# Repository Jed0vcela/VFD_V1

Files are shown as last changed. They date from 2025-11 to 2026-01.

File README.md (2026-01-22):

VFD driver for IVL1-8/13 soviet display.
Powered form 5V USB.
SPI interface that can be daisy-chained.
3,3V logic level.
Analog dimming via adjusting anode voltage.
Heater voltage adjustment implemented on board but not tested




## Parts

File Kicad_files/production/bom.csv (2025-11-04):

Designator | Footprint | Quantity | Value | LCSC Part #
27V1, 3V1, 8V1, GND1 | TestPoint_Pad_D1.0mm | 4 | TestPoint_Probe
C1, C4, C9 | 1206 | 3 | 1u
C12, C13, C14, C15 | 0805 | 4 | 100n
C2 | CP_Radial_D8.0mm_P5.00mm | 1 | 470u
C5, C6 | 0805 | 2 | 470p
C8 | CP_Radial_D8.0mm_P5.00mm | 1 | 100u
D1, D3, D4, D5 | D_SOD-323_HandSoldering | 4 | LL4148
J1 | PinHeader_1x08_P2.54mm_Horizontal | 1 | Conn_01x08_Pin
J2 | PinSocket_1x08_P2.54mm_Horizontal | 1 | Conn_01x08_Socket
L1 | L_7.3x7.3_H4.5 | 1 | DE1205-330
Q1, Q10, Q12, Q14, Q16, Q18, Q19, Q2, Q21, Q23, Q25, Q27, Q29, Q31, Q33, Q35, Q36, Q38, Q4, Q40, Q42, Q44, Q46, Q48, Q50, Q6, Q8 | SOT-23 | 27 | BC846
Q11, Q13, Q15, Q17, Q20, Q22, Q24, Q26, Q28, Q3, Q30, Q32, Q34, Q37, Q39, Q41, Q43, Q45, Q47, Q49, Q5, Q51, Q7, Q9 | SOT-23 | 24 | BC856
R1 | 0805 | 1 | 1,8
R10 | 0805 | 1 | 470k
R11 | 0805 | 1 | 220k
R12, R15, R17, R18, R22, R23, R24, R25, R26, R28, R29, R30, R40, R41, R42, R43, R44, R46, R47, R48, R57, R58, R59, R60, R61, R63, R64, R65, R8 | 0805 | 29 | 100k
R13 | 0805 | 1 | 22k
R19 | 0805 | 1 | 56k
R2 | 0805 | 1 | 470m
R20 | 0805 | 1 | 27k
R21, R39, R56 | 0805 | 3 | 10k
R3, R4 | 0805 | 2 | 180
R5 | 0805 | 1 | 1M
R6, R7 | 0805 | 2 | 0
R9 | 0805 | 1 | 4k7
U10, U11, U8 | SOIC-16_3.9x9.9mm_P1.27mm | 3 | ULN2003
U2 | SOIC-8_3.9x4.9mm_P1.27mm | 1 | MC34063AD
U4 | IVL1-813 | 1 | IVL1-8/13
U5, U6, U7, U9 | SOIC-16_3.9x9.9mm_P1.27mm | 4 | 74AHC595

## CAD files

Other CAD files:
Kicad_files/3D files/M1005_cap_004.SLDASM
Kicad_files/3D files/Side_metal001.SLDASM
Kicad_files/3D files/M1005_res_0.2_001.SLDASM
Kicad_files/3D files/Side.SLDASM
Kicad_files/3D files/M0603_cap_0.3_007.SLDASM
Kicad_files/3D files/RT6154AGQW.SLDASM
Kicad_files/3D files/Pins001.SLDASM
Kicad_files/3D files/M1005_cap_003.SLDASM
Kicad_files/3D files/Misc.SLDASM
Kicad_files/3D files/Button_v2.SLDASM
Kicad_files/3D files/LED_M1608.SLDASM
Kicad_files/3D files/Pins1.SLDASM
Kicad_files/3D files/Part006.SLDASM
Kicad_files/3D files/M0603_cap_0.3_001.SLDASM
Kicad_files/3D files/M0603_cap_0.3_003.SLDASM
Kicad_files/3D files/M2012_cap003.SLDASM
Kicad_files/3D files/Part005.SLDASM
Kicad_files/3D files/Part004.SLDASM
Kicad_files/3D files/0C-138.SLDPRT
Kicad_files/3D files/1.15.SLDPRT
Kicad_files/3D files/2.SLDPRT
Kicad_files/3D files/2001.SLDPRT
Kicad_files/3D files/3V3.SLDPRT
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

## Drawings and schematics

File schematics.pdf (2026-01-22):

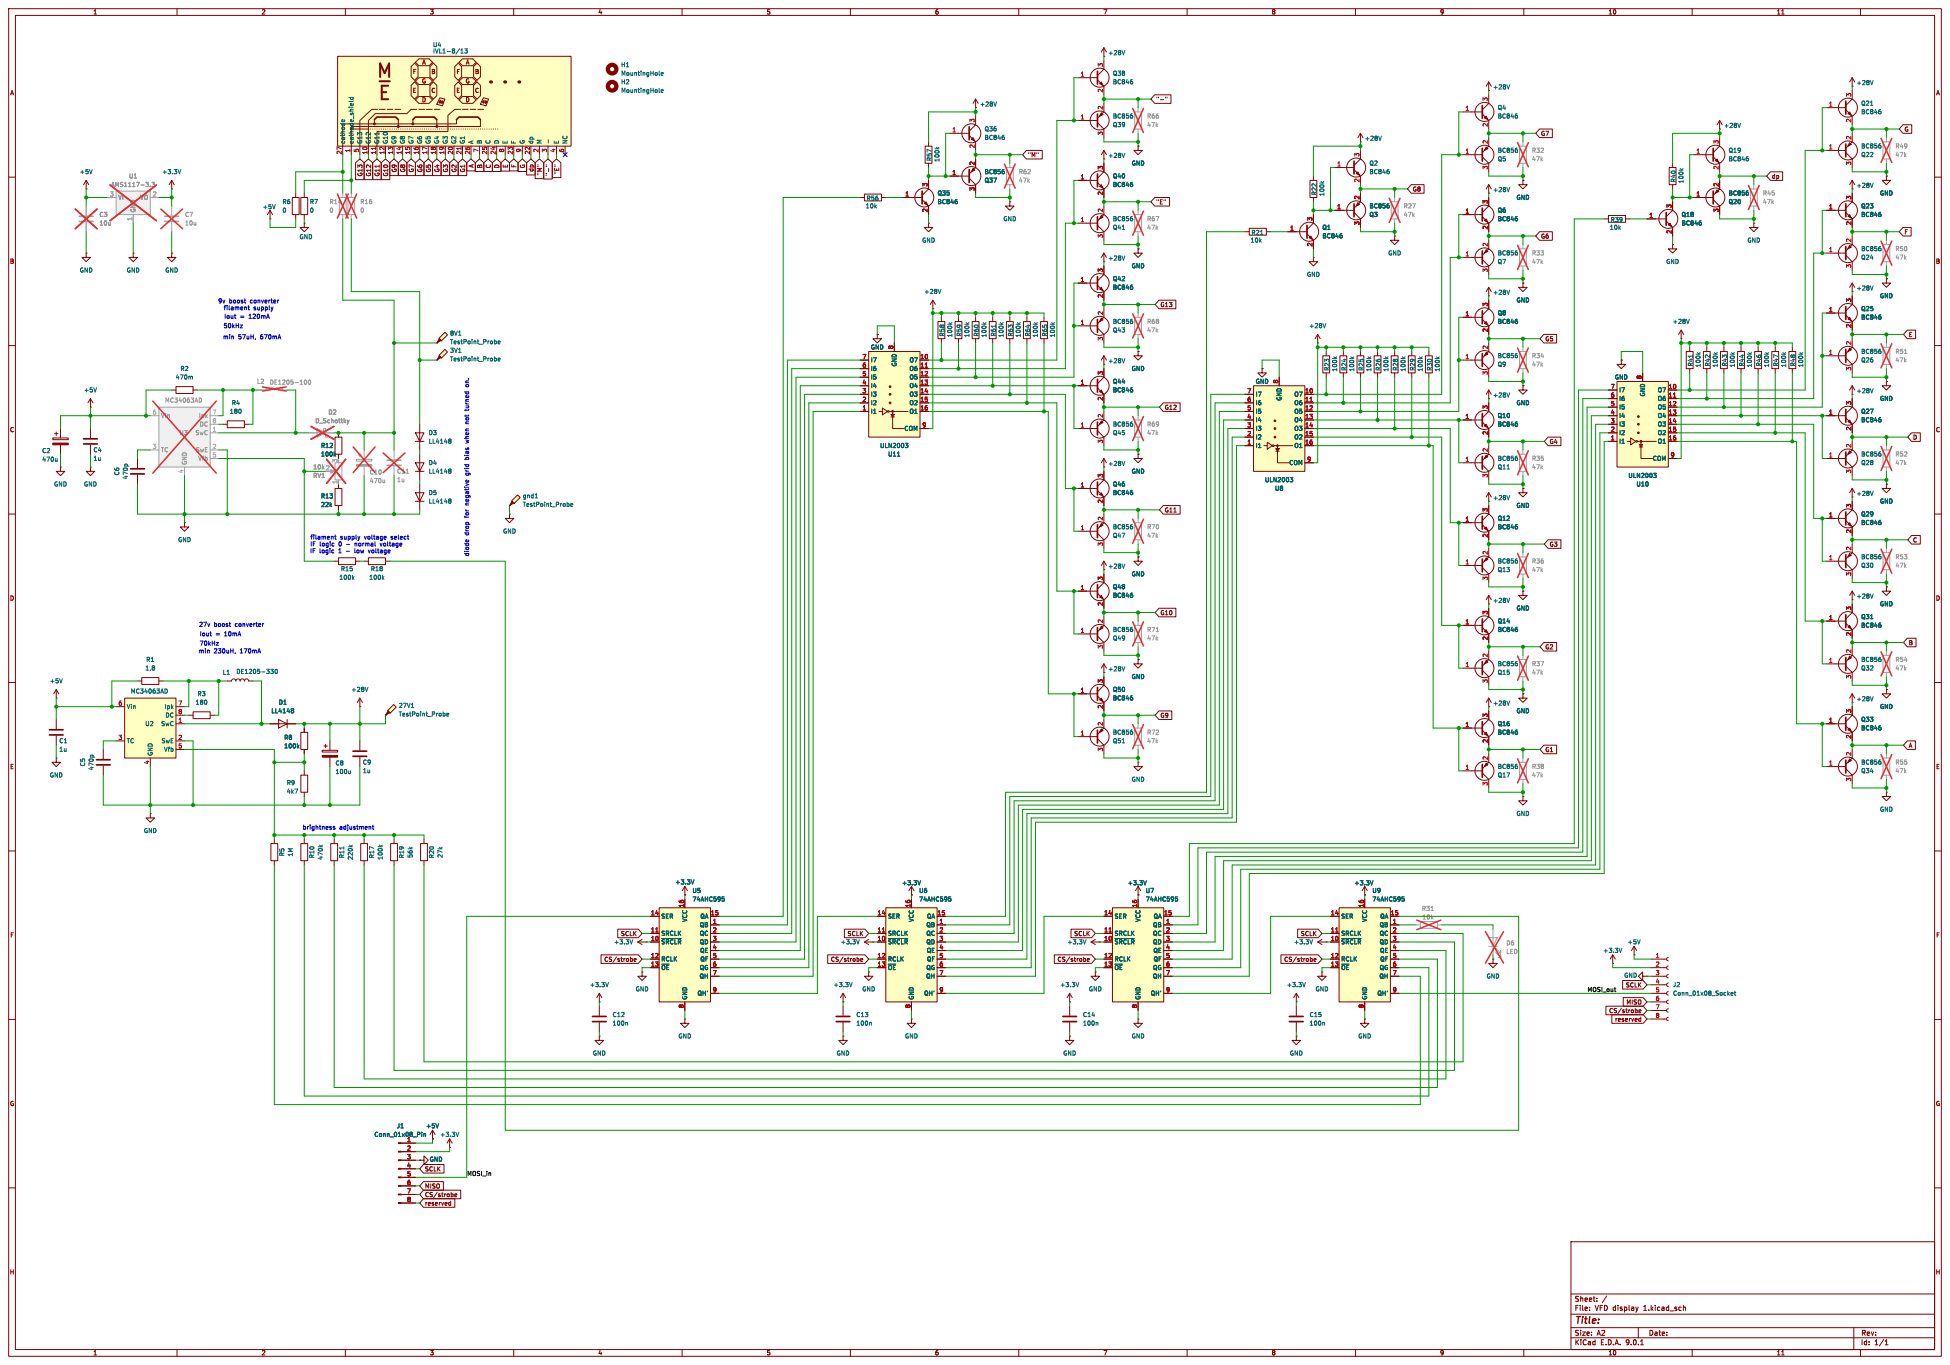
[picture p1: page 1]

Ipk 7 DC 8 SwC 1 SwE 2 Vfb 5 U3 MC34063AD

IF logic 0 - normal voltage

Ipk 7 DC 8 SwC 1 SwE 2 Vfb 5 U2 MC34063AD C5 470p GND

74AHC595

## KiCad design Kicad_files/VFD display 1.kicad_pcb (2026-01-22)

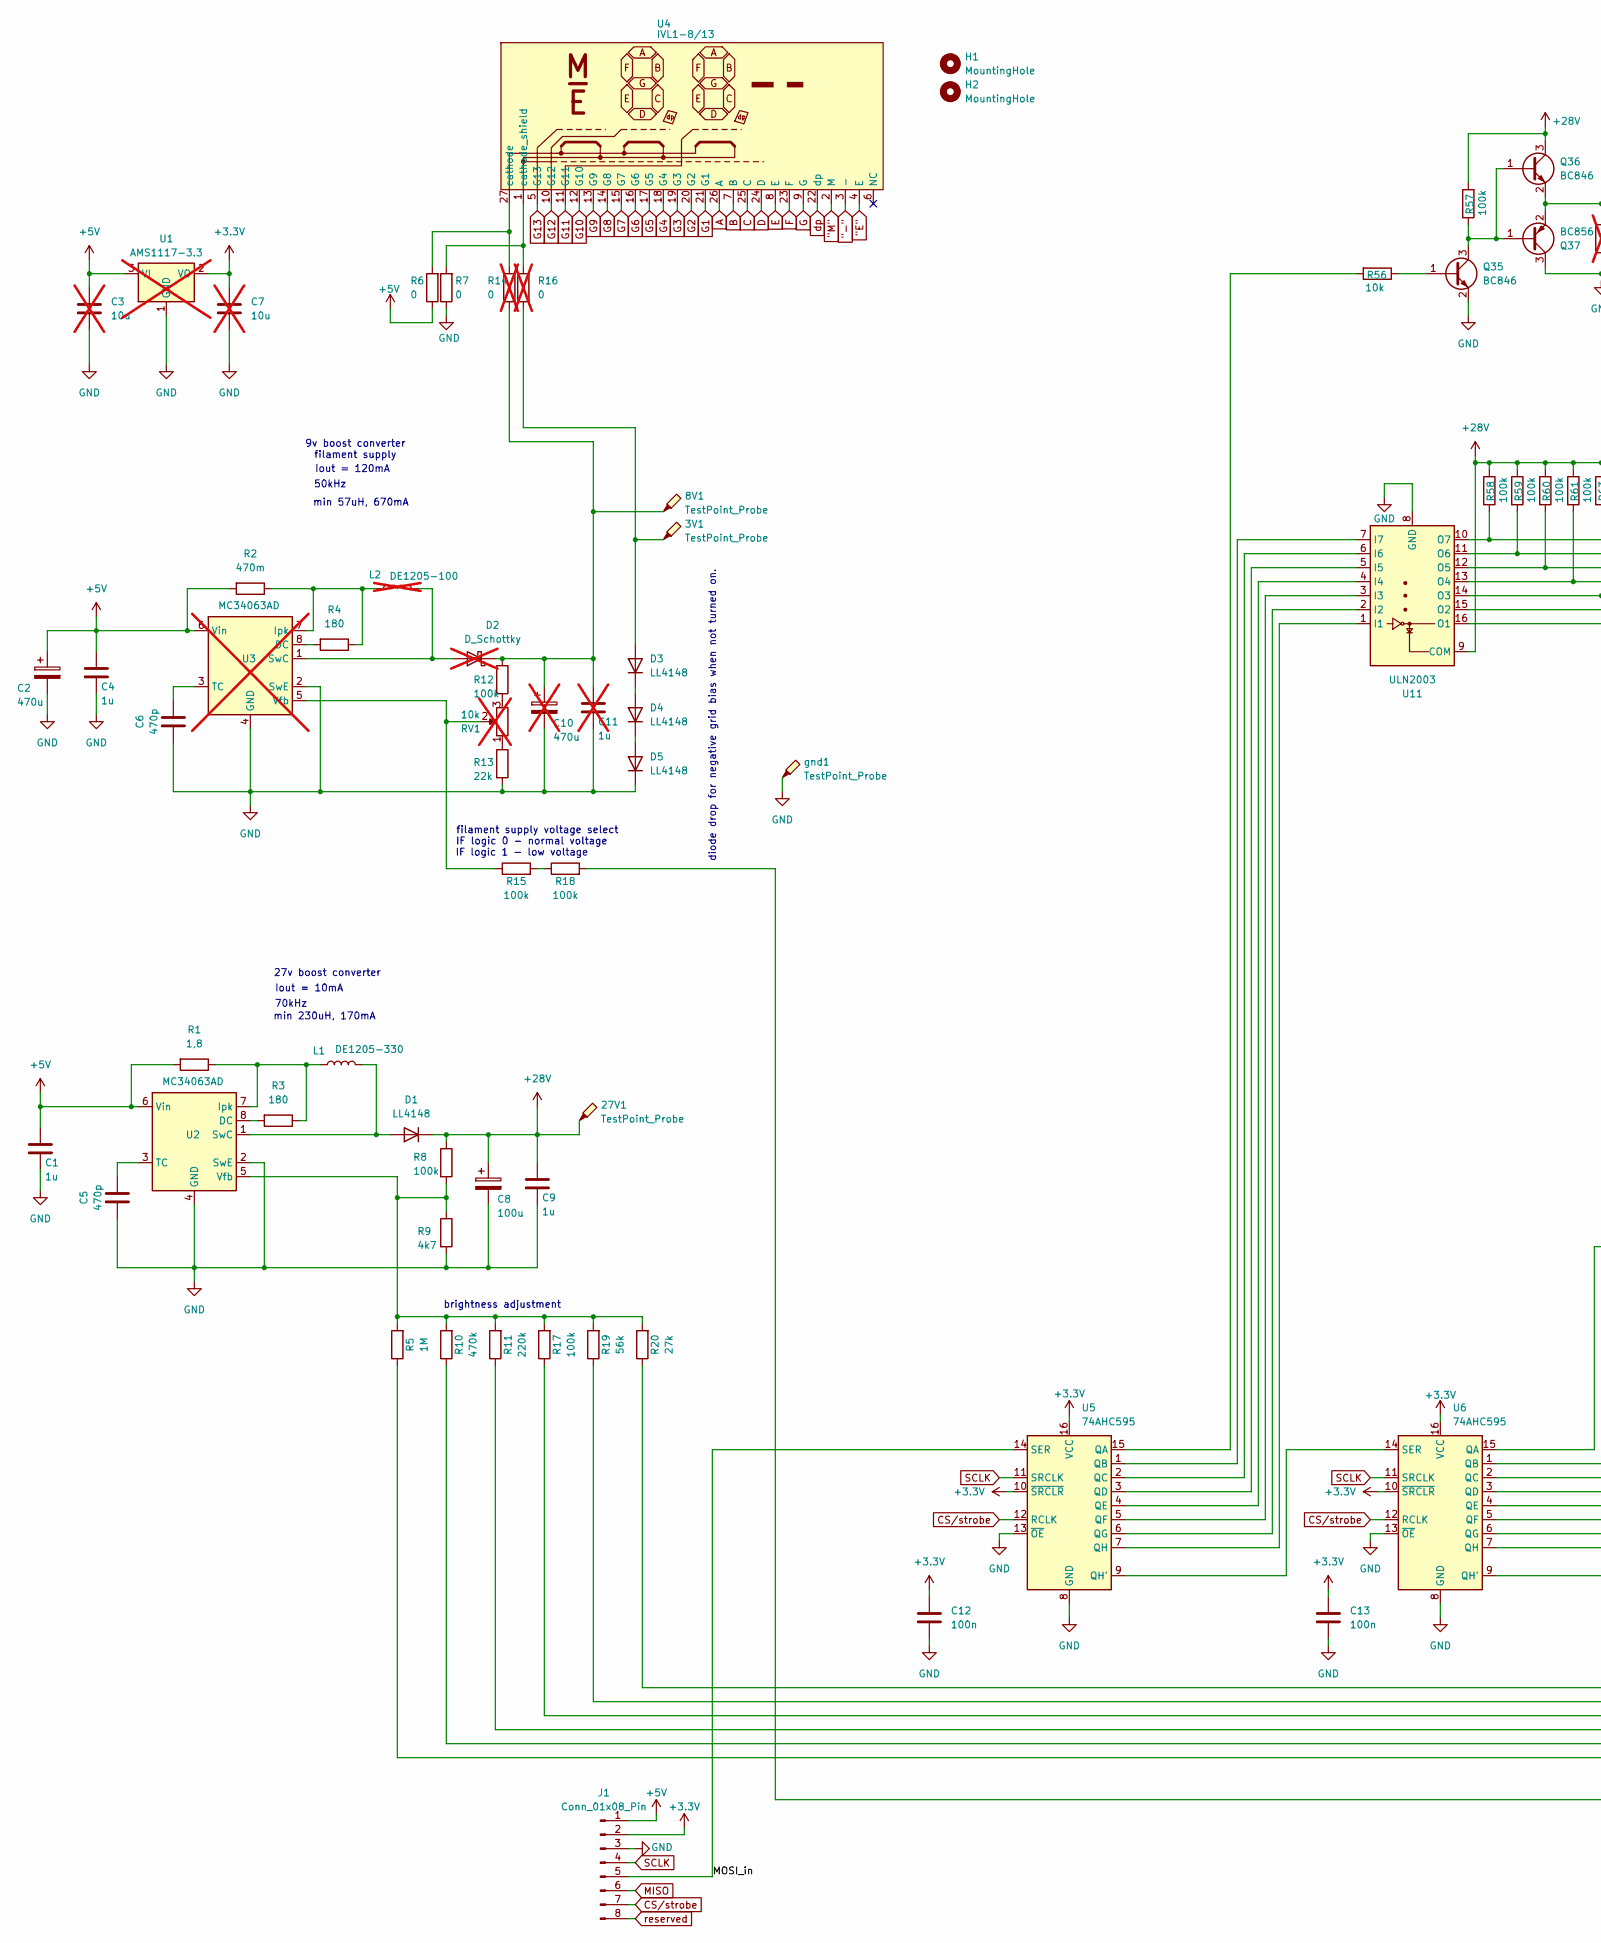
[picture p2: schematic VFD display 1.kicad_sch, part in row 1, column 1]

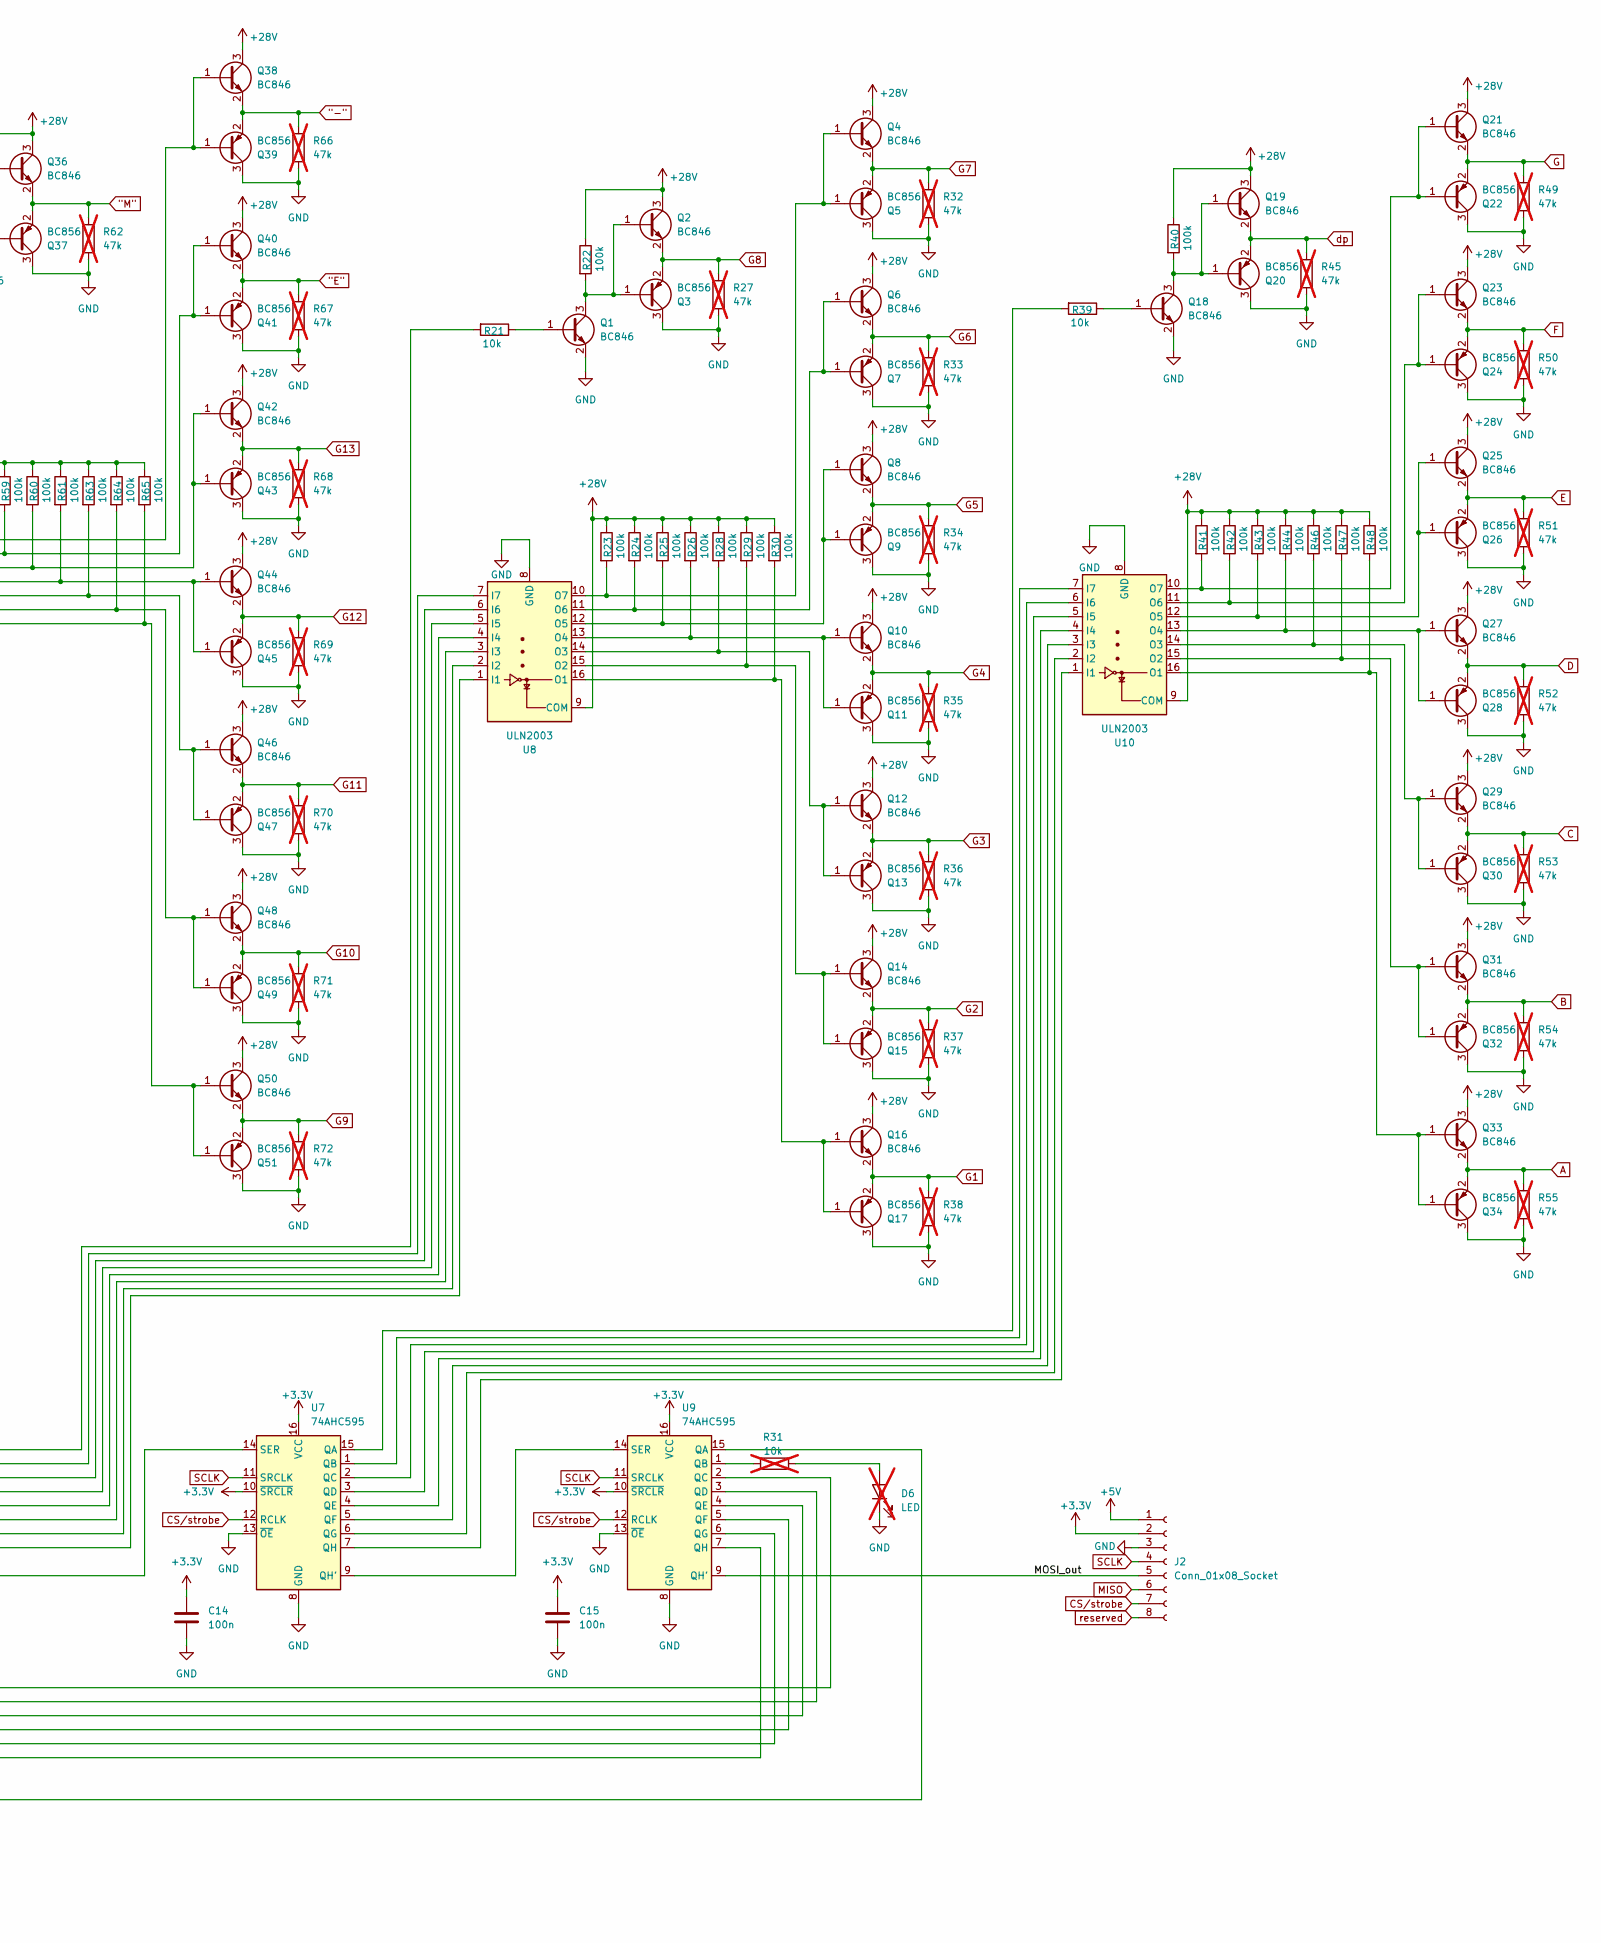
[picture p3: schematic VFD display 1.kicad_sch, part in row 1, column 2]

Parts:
3V1, 8V1, 27V1: TestPoint_Probe; TestPoint_Pad_D1.0mm
C1, C4, C9: 1u; C_1206_3216Metric_Pad1.33x1.80mm_HandSolder
C2: 470u; CP_Radial_D8.0mm_P5.00mm
C3, C7: 10u; C_0805_2012Metric; not fitted
C5, C6: 470p; C_0805_2012Metric
C8: 100u; CP_Radial_D8.0mm_P5.00mm
C10: 470u; CP_Radial_D8.0mm_P5.00mm; not fitted
C11: 1u; C_1206_3216Metric_Pad1.33x1.80mm_HandSolder; not fitted
C12, C13, C14, C15: 100n; C_0805_2012Metric_Pad1.18x1.45mm_HandSolder
D1, D3, D4, D5: LL4148; D_SOD-323_HandSoldering
D2: D_Schottky; D_SMA; not fitted
D6: LED; LED_0805_2012Metric; not fitted
H1, H2: MountingHole; MountingHole_3.2mm_M3_DIN965
J1: Conn_01x08_Pin; PinHeader_1x08_P2.54mm_Horizontal
J2: Conn_01x08_Socket; PinSocket_1x08_P2.54mm_Horizontal
L1: DE1205-330; L_7.3x7.3_H4.5
L2: DE1205-100; L_12x12mm_H6mm; not fitted
Q1, Q2, Q4, Q6, Q8, Q10, Q12, Q14, Q16, Q18, Q19, Q21, Q23, Q25, Q27, Q29, Q31, Q33, Q35, Q36, Q38, Q40, Q42, Q44, Q46, Q48, Q50: BC846; SOT-23
Q3, Q5, Q7, Q9, Q11, Q13, Q15, Q17, Q20, Q22, Q24, Q26, Q28, Q30, Q32, Q34, Q37, Q39, Q41, Q43, Q45, Q47, Q49, Q51: BC856; SOT-23
R1: 1,8; R_0805_2012Metric
R2: 470m; R_0805_2012Metric
R3, R4: 180; R_0805_2012Metric
R5: 1M; R_0805_2012Metric_Pad1.20x1.40mm_HandSolder
R6, R7: 0; R_0805_2012Metric_Pad1.20x1.40mm_HandSolder
R8, R12: 100k; R_0805_2012Metric
R9: 4k7; R_0805_2012Metric
R10: 470k; R_0805_2012Metric_Pad1.20x1.40mm_HandSolder
R11: 220k; R_0805_2012Metric_Pad1.20x1.40mm_HandSolder
R13: 22k; R_0805_2012Metric
R14, R16: 0; R_0805_2012Metric_Pad1.20x1.40mm_HandSolder; not fitted
R15, R17, R18, R22, R23, R24, R25, R26, R28, R29, R30, R40, R41, R42, R43, R44, R46, R47, R48, R57, R58, R59, R60, R61, R63, R64, R65: 100k; R_0805_2012Metric_Pad1.20x1.40mm_HandSolder
R19: 56k; R_0805_2012Metric_Pad1.20x1.40mm_HandSolder
R20: 27k; R_0805_2012Metric_Pad1.20x1.40mm_HandSolder
R21, R39, R56: 10k; R_0805_2012Metric_Pad1.20x1.40mm_HandSolder
R27, R32, R33, R34, R35, R36, R37, R38, R45, R49, R50, R51, R52, R53, R54, R55, R62, R66, R67, R68, R69, R70, R71, R72: 47k; R_0805_2012Metric_Pad1.20x1.40mm_HandSolder; not fitted
R31: 10k; R_0805_2012Metric_Pad1.20x1.40mm_HandSolder; not fitted
RV1: 10k; Potentiometer_Piher_PT-6-V_Vertical_Hole; not fitted
U1: AMS1117-3.3; SOT-223-3_TabPin2; not fitted
U2: MC34063AD; SOIC-8_3.9x4.9mm_P1.27mm
U3: MC34063AD; SOIC-8_3.9x4.9mm_P1.27mm; not fitted
U4: IVL1-8/13; IVL1-813
U5, U6, U7, U9: 74AHC595; SOIC-16_3.9x9.9mm_P1.27mm
U8, U10, U11: ULN2003; SOIC-16_3.9x9.9mm_P1.27mm
gnd1: TestPoint_Probe; TestPoint_Pad_D1.0mm

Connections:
"-": Q38.2 (E), Q39.2 (E), R66.1, U4.3 (-)
"E": Q40.2 (E), Q41.2 (E), R67.1, U4.4 (E)
"M": Q36.2 (E), Q37.2 (E), R62.1, U4.2 (M)
+3.3V: C7.1, C12.1, C13.1, C14.1, C15.1, J1.2, J2.2, U1.2 (VO), U5.10 (~SRCLR), U5.16 (VCC), U6.10 (~SRCLR), U6.16 (VCC), U7.10 (~SRCLR), U7.16 (VCC), U9.10 (~SRCLR), U9.16 (VCC)
+5V: C1.1, C2.1, C3.1, C4.1, J1.1, J2.1, R1.2, R2.2, R6.1, U1.3 (VI), U2.6 (Vin), U3.6 (Vin)
+28V: 27V1.1, C8.1, C9.1, D1.1 (K), Q2.3 (C), Q4.3 (C), Q6.3 (C), Q8.3 (C), Q10.3 (C), Q12.3 (C), Q14.3 (C), Q16.3 (C), Q19.3 (C), Q21.3 (C), Q23.3 (C), Q25.3 (C), Q27.3 (C), Q29.3 (C), Q31.3 (C), Q33.3 (C), Q36.3 (C), Q38.3 (C), Q40.3 (C), Q42.3 (C), Q44.3 (C), Q46.3 (C), Q48.3 (C), Q50.3 (C), R8.1, R22.1, R23.1, R24.1, R25.1, R26.1, R28.1, R29.1, R30.1, R40.1, R41.1, R42.1, R43.1, R44.1, R46.1, R47.1, R48.1, R57.1, R58.1, R59.1, R60.1, R61.1, R63.1, R64.1, R65.1, U8.9 (COM), U10.9 (COM), U11.9 (COM)
/MOSI_in: J1.5, U5.14 (SER)
/MOSI_out: J2.5, U9.9 (QH')
A: Q33.2 (E), Q34.2 (E), R55.1, U4.26 (A)
B: Q31.2 (E), Q32.2 (E), R54.1, U4.7 (B)
C: Q29.2 (E), Q30.2 (E), R53.1, U4.25 (C)
CS/strobe: J1.7, J2.7, U5.12 (RCLK), U6.12 (RCLK), U7.12 (RCLK), U9.12 (RCLK)
D: Q27.2 (E), Q28.2 (E), R52.1, U4.24 (D)
E: Q25.2 (E), Q26.2 (E), R51.1, U4.8 (E)
F: Q23.2 (E), Q24.2 (E), R50.1, U4.23 (F)
G: Q21.2 (E), Q22.2 (E), R49.1, U4.9 (G)
G1: Q16.2 (E), Q17.2 (E), R38.1, U4.21 (G1)
G2: Q14.2 (E), Q15.2 (E), R37.1, U4.20 (G2)
G3: Q12.2 (E), Q13.2 (E), R36.1, U4.19 (G3)
G4: Q10.2 (E), Q11.2 (E), R35.1, U4.18 (G4)
G5: Q8.2 (E), Q9.2 (E), R34.1, U4.17 (G5)
G6: Q6.2 (E), Q7.2 (E), R33.1, U4.16 (G6)
G7: Q4.2 (E), Q5.2 (E), R32.1, U4.15 (G7)
G8: Q2.2 (E), Q3.2 (E), R27.1, U4.14 (G8)
G9: Q50.2 (E), Q51.2 (E), R72.1, U4.13 (G9)
G10: Q48.2 (E), Q49.2 (E), R71.1, U4.12 (G10)
G11: Q46.2 (E), Q47.2 (E), R70.1, U4.11 (G11)
G12: Q44.2 (E), Q45.2 (E), R69.1, U4.10 (G12)
G13: Q42.2 (E), Q43.2 (E), R68.1, U4.5 (G13)
GND: C1.2, C2.2, C3.2, C4.2, C5.1, C6.1, C7.2, C8.2, C9.2, C10.2, C11.2, C12.2, C13.2, C14.2, C15.2, D5.1 (K), D6.1 (K), J1.3, J2.3, Q1.2 (E), Q3.3 (C), Q5.3 (C), Q7.3 (C), Q9.3 (C), Q11.3 (C), Q13.3 (C), Q15.3 (C), Q17.3 (C), Q18.2 (E), Q20.3 (C), Q22.3 (C), Q24.3 (C), Q26.3 (C), Q28.3 (C), Q30.3 (C), Q32.3 (C), Q34.3 (C), Q35.2 (E), Q37.3 (C), Q39.3 (C), Q41.3 (C), Q43.3 (C), Q45.3 (C), Q47.3 (C), Q49.3 (C), Q51.3 (C), R7.1, R9.2, R13.2, R27.2, R32.2, R33.2, R34.2, R35.2, R36.2, R37.2, R38.2, R45.2, R49.2, R50.2, R51.2, R52.2, R53.2, R54.2, R55.2, R62.2, R66.2, R67.2, R68.2, R69.2, R70.2, R71.2, R72.2, U1.1 (GND), U2.2 (SwE), U2.4 (GND), U3.2 (SwE), U3.4 (GND), U5.8 (GND), U5.13 (~OE), U6.8 (GND), U6.13 (~OE), U7.8 (GND), U7.13 (~OE), U8.8 (GND), U9.8 (GND), U9.13 (~OE), U10.8 (GND), U11.8 (GND), gnd1.1
MISO: J1.6, J2.6
unnamed: D1.2 (A), L1.2, U2.1 (SwC)
unnamed: D2.2 (A), L2.2, U3.1 (SwC)
unnamed: 8V1.1, C10.1, C11.1, D2.1 (K), R12.1, R14.1
unnamed: 3V1.1, D3.2 (A), R16.1
unnamed: D3.1 (K), D4.2 (A)
unnamed: D4.1 (K), D5.2 (A)
unnamed: D6.2 (A), R31.2
unnamed: Q1.1 (B), R21.1
unnamed: Q1.3 (C), Q2.1 (B), Q3.1 (B), R22.2
unnamed: Q4.1 (B), Q5.1 (B), R23.2, U8.10 (O7)
unnamed: Q6.1 (B), Q7.1 (B), R24.2, U8.11 (O6)
unnamed: Q8.1 (B), Q9.1 (B), R25.2, U8.12 (O5)
unnamed: Q10.1 (B), Q11.1 (B), R26.2, U8.13 (O4)
unnamed: Q12.1 (B), Q13.1 (B), R28.2, U8.14 (O3)
unnamed: Q14.1 (B), Q15.1 (B), R29.2, U8.15 (O2)
unnamed: Q16.1 (B), Q17.1 (B), R30.2, U8.16 (O1)
unnamed: Q18.1 (B), R39.1
unnamed: Q18.3 (C), Q19.1 (B), Q20.1 (B), R40.2
unnamed: Q21.1 (B), Q22.1 (B), R41.2, U10.10 (O7)
unnamed: Q23.1 (B), Q24.1 (B), R42.2, U10.11 (O6)
unnamed: Q25.1 (B), Q26.1 (B), R43.2, U10.12 (O5)
unnamed: Q27.1 (B), Q28.1 (B), R44.2, U10.13 (O4)
unnamed: Q29.1 (B), Q30.1 (B), R46.2, U10.14 (O3)
unnamed: Q31.1 (B), Q32.1 (B), R47.2, U10.15 (O2)
unnamed: Q33.1 (B), Q34.1 (B), R48.2, U10.16 (O1)
unnamed: Q35.1 (B), R56.1
unnamed: Q35.3 (C), Q36.1 (B), Q37.1 (B), R57.2
unnamed: Q38.1 (B), Q39.1 (B), R58.2, U11.10 (O7)
unnamed: Q40.1 (B), Q41.1 (B), R59.2, U11.11 (O6)
unnamed: Q42.1 (B), Q43.1 (B), R60.2, U11.12 (O5)
unnamed: Q44.1 (B), Q45.1 (B), R61.2, U11.13 (O4)
unnamed: Q46.1 (B), Q47.1 (B), R63.2, U11.14 (O3)
unnamed: Q48.1 (B), Q49.1 (B), R64.2, U11.15 (O2)
unnamed: Q50.1 (B), Q51.1 (B), R65.2, U11.16 (O1)
unnamed: R12.2, RV1.3
unnamed: R13.1, RV1.1
unnamed: R15.2, R18.1
unnamed: R3.2, U2.8 (DC)
unnamed: L1.1, R1.1, R3.1, U2.7 (Ipk)
unnamed: C5.2, U2.3 (TC)
unnamed: R5.2, R8.2, R9.1, R10.2, R11.2, R17.2, R19.2, R20.2, U2.5 (Vfb)
unnamed: R4.2, U3.8 (DC)
unnamed: L2.1, R2.1, R4.1, U3.7 (Ipk)
unnamed: C6.2, U3.3 (TC)
unnamed: R15.1, RV1.2, U3.5 (Vfb)
unnamed: R6.2, R14.2, U4.27 (cathode)
unnamed: R7.2, R16.2, U4.1 (cathode_shield)
unnamed: R56.2, U5.15 (QA)
unnamed: U5.9 (QH'), U6.14 (SER)
unnamed: R21.2, U6.15 (QA)
unnamed: U6.1 (QB), U8.7 (I7)
unnamed: U6.2 (QC), U8.6 (I6)
unnamed: U6.3 (QD), U8.5 (I5)
unnamed: U6.4 (QE), U8.4 (I4)
unnamed: U6.5 (QF), U8.3 (I3)
unnamed: U6.6 (QG), U8.2 (I2)
unnamed: U6.9 (QH'), U7.14 (SER)
unnamed: U6.7 (QH), U8.1 (I1)
unnamed: R39.2, U7.15 (QA)
unnamed: U7.9 (QH'), U9.14 (SER)
unnamed: R18.2, U9.15 (QA)
unnamed: R31.1, U9.1 (QB)
unnamed: R20.1, U9.2 (QC)
unnamed: R19.1, U9.3 (QD)
unnamed: R17.1, U9.4 (QE)
unnamed: R11.1, U9.5 (QF)
unnamed: R10.1, U9.6 (QG)
unnamed: R5.1, U9.7 (QH)
unnamed: U7.7 (QH), U10.1 (I1)
unnamed: U7.6 (QG), U10.2 (I2)
unnamed: U7.5 (QF), U10.3 (I3)
unnamed: U7.4 (QE), U10.4 (I4)
unnamed: U7.3 (QD), U10.5 (I5)
unnamed: U7.2 (QC), U10.6 (I6)
unnamed: U7.1 (QB), U10.7 (I7)
unnamed: U5.7 (QH), U11.1 (I1)
unnamed: U5.6 (QG), U11.2 (I2)
unnamed: U5.5 (QF), U11.3 (I3)
unnamed: U5.4 (QE), U11.4 (I4)
unnamed: U5.3 (QD), U11.5 (I5)
unnamed: U5.2 (QC), U11.6 (I6)
unnamed: U5.1 (QB), U11.7 (I7)
SCLK: J1.4, J2.4, U5.11 (SRCLK), U6.11 (SRCLK), U7.11 (SRCLK), U9.11 (SRCLK)
dp: Q19.2 (E), Q20.2 (E), R45.1, U4.22 (dp)
reserved: J1.8, J2.8

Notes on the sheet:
70kHz
50kHz
min 230uH, 170mA
filament supply voltage select
Iout = 120mA
min 57uH, 670mA
27v boost converter
diode drop for negative grid bias when not turned on.
9v boost converter filament supply
brightness adjustment
IF logic 0 - normal voltage
IF logic 1 - low voltage
Iout = 10mA

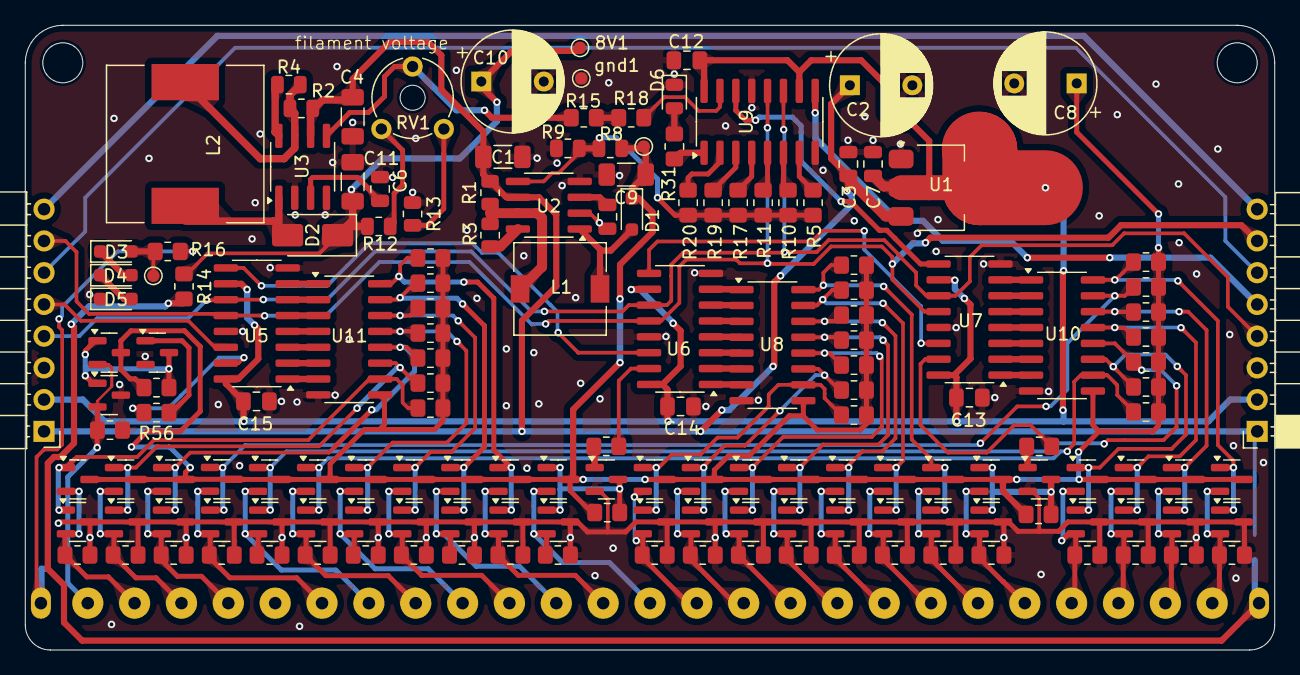
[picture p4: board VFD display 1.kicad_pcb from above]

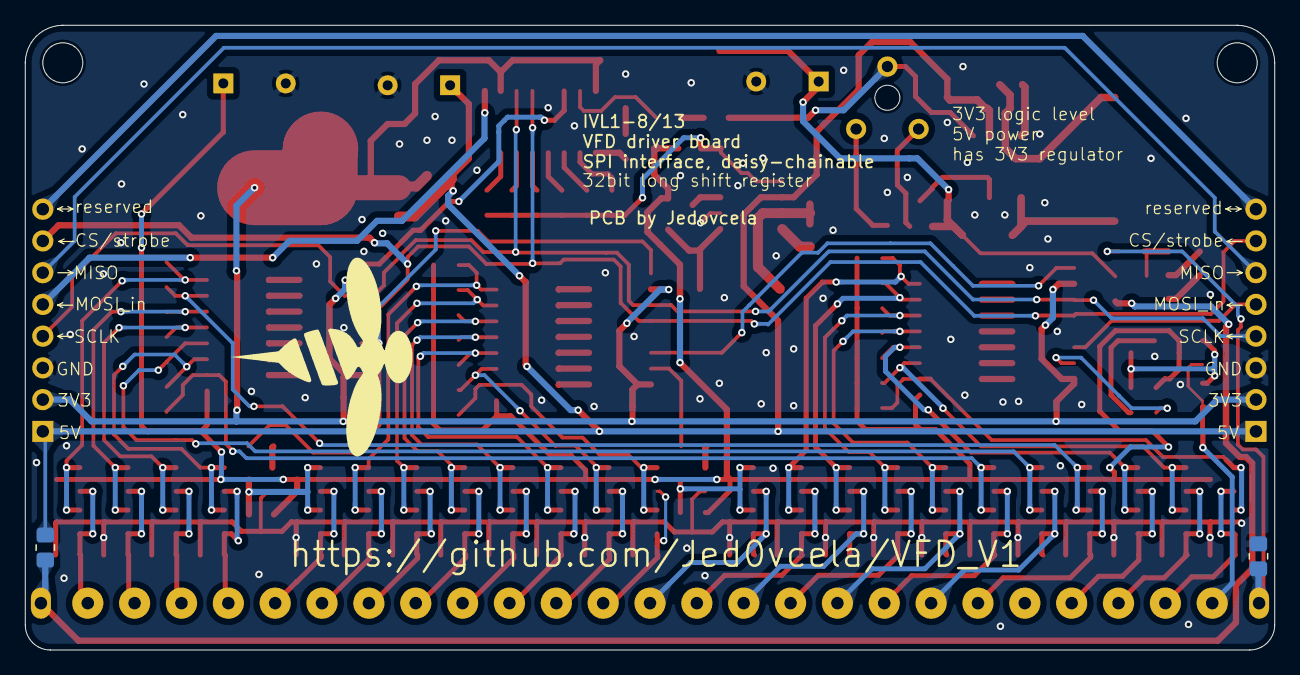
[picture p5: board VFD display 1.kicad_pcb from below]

Board: 2 copper layers, 100.0 x 50.0 mm, 166 parts (2 on the bottom side), 116 nets.

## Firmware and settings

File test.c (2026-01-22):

#include <stdio.h>
#include "pico/stdlib.h"
#include "hardware/spi.h"

// SPI pins
#define PIN_SCK  2
#define PIN_MOSI 3
#define PIN_MISO 4  // unused but needed for SPI init
#define PIN_CS   5  // latch pin

// Button pins (active low with pullup)
#define BTN_TIME_UP    17
#define BTN_TIME_DOWN  18
#define BTN_BRIGHT_UP  21
#define BTN_BRIGHT_DOWN 22

// SPI instance
#define SPI_PORT spi0
#define SPI_BAUDRATE 1000000  // 1 MHz

// Display parameters
#define NUM_DIGITS 13
#define NUM_SPECIAL 3

// Special character bit positions (bits 0-2 in digit mask after rotation)
#define SPECIAL_M_BIT 0  // "M" character (last bit sent over SPI)
#define SPECIAL_DASH_BIT 1  // "-" character
#define SPECIAL_E_BIT 2  // "E" character

// Digit positions are shifted right by 3 (bits 3-15)
#define DIGIT_BIT_OFFSET 3

// Global variables
uint8_t brightness = 30;  // 0-63
uint8_t digit = 0;

int32_t time_offset_seconds = 0;  // User adjustment

// Special character enable flags
bool special_m_enabled = false;
bool special_dash_enabled = false;
bool special_e_enabled = false;

// Button state tracking
typedef struct {
    uint8_t pin;
    bool pressed;
    uint32_t press_start_time;
    uint32_t last_action_time;
    uint32_t hold_count;
} button_state_t;

button_state_t btn_time_up = {BTN_TIME_UP, false, 0, 0, 0};
button_state_t btn_time_down = {BTN_TIME_DOWN, false, 0, 0, 0};
button_state_t btn_bright_up = {BTN_BRIGHT_UP, false, 0, 0, 0};
button_state_t btn_bright_down = {BTN_BRIGHT_DOWN, false, 0, 0, 0};

// 7-segment lookup table
const uint8_t seg7[12] = {
    0x11,        // 0
    0b11011011,  // 1
    0b01000101,  // 2
    0b01001001,  // 3
    0b10001011,  // 4
    0b00101001,  // 5
    0b00100001,  // 6
    0b01011011,  // 7
    0x01,        // 8
    0x09,        // 9
    0xff,        // blank
    0xfe         // dash
};

// Bit reversal table for 6-bit values
const uint8_t rev6[64] = {
    0,32,16,48,8,40,24,56,4,36,20,52,12,44,28,60,
    2,34,18,50,10,42,26,58,6,38,22,54,14,46,30,62,
    1,33,17,49,9,41,25,57,5,37,21,53,13,45,29,61,
    3,35,19,51,11,43,27,59,7,39,23,55,15,47,31,63
};

// Number array for 13 digits, initialization
uint8_t number[NUM_DIGITS] = {10,10,10,10,4,5,6,7,8,9,5,7,3};

/**
 * Send 32 bits via SPI and pulse latch pin
 */
void send_32bit(uint32_t value) {
    uint8_t buf[4];
    
    // Split into 4 bytes (MSB first)
    buf[0] = (value >> 24) & 0xFF;
    buf[1] = (value >> 16) & 0xFF;
    buf[2] = (value >> 8)  & 0xFF;
    buf[3] = value & 0xFF;
    
    // Send via SPI
    spi_write_blocking(SPI_PORT, buf, 4);
    
    // Pulse latch/CS pin
    gpio_put(PIN_CS, 1);
    sleep_us(1);
    gpio_put(PIN_CS, 0);
}

/**
 * Send display data for one digit (0-12)
 */
void send_display_digit(uint8_t dig) {
    uint32_t bright, num, dig_mask, frame;
    
    // Clamp brightness to 6 bits
    if (brightness > 63) {
        brightness = 63;
    }
    
    // Reverse brightness bits and shift to position [31:26]
    bright = rev6[brightness];
    bright = bright << 26;
    bright = (~bright) & 0xFC000000;
    
    uint8_t tmp_num = number[dig];
    
    // Segment data in bits [23:16]
    num = ((uint32_t)seg7[tmp_num]) << 16;
    
    // Digit mask: digits are in bits [15:3], special chars in bits [2:0]
    dig_mask = 1 << (dig + DIGIT_BIT_OFFSET);
    dig_mask = (~dig_mask) & 0x0000FFF8;

    uint32_t special = (!special_e_enabled << 2) | (!special_dash_enabled << 1) | !special_m_enabled;

    // Combine and send
    frame = bright + num + dig_mask + special;
    send_32bit(frame);
}

/**
 * Update a specific digit value
 */
void set_digit_value(uint8_t pos, uint8_t value) {
    if (pos < NUM_DIGITS) {
        number[pos] = value;
    }
}

/**
 * Set brightness (0-63)
 */
void set_brightness(uint8_t bright) {
    if (bright > 63) {
        bright = 63;
    }
    brightness = bright;
}

/**
 * Initialize buttons with pullup
 */
void init_buttons(void) {
    gpio_init(BTN_TIME_UP);
    gpio_set_dir(BTN_TIME_UP, GPIO_IN);
    gpio_pull_up(BTN_TIME_UP);
    
    gpio_init(BTN_TIME_DOWN);
    gpio_set_dir(BTN_TIME_DOWN, GPIO_IN);
    gpio_pull_up(BTN_TIME_DOWN);
    
    gpio_init(BTN_BRIGHT_UP);
    gpio_set_dir(BTN_BRIGHT_UP, GPIO_IN);
    gpio_pull_up(BTN_BRIGHT_UP);
    
    gpio_init(BTN_BRIGHT_DOWN);
    gpio_set_dir(BTN_BRIGHT_DOWN, GPIO_IN);
    gpio_pull_up(BTN_BRIGHT_DOWN);
}

/**
 * Calculate time adjustment with smooth linear acceleration
 * Returns number of seconds to adjust based on hold duration
 */
int32_t calculate_time_adjustment(uint32_t hold_count) {
    // Linear acceleration: starts at 1 second, increases smoothly
    
    int32_t adjustment = 1 + (hold_count / 2);
    
    return adjustment;
}

/**
 * Process button state with debouncing and acceleration
 */
void process_button(button_state_t *btn) {
    bool current_state = !gpio_get(btn->pin);  // Active low, so invert
    uint32_t now = to_ms_since_boot(get_absolute_time());
    
    if (current_state && !btn->pressed) {
        // Button just pressed
        btn->pressed = true;
        btn->press_start_time = now;
        btn->last_action_time = now;
        btn->hold_count = 0;
    } else if (!current_state && btn->pressed) {
        // Button released
        btn->pressed = false;
        btn->hold_count = 0;
    }
}

/**
 * Handle time adjustment buttons with smooth acceleration
 */
void handle_time_buttons(void) {
    uint32_t now = to_ms_since_boot(get_absolute_time());
    
    // Process button states
    process_button(&btn_time_up);
    process_button(&btn_time_down);
    
    // Handle time up
    if (btn_time_up.pressed) {
        uint32_t interval = 100;  // Base interval: 100ms (10 Hz)
        
        // Gradually speed up the repeat rate for smoother acceleration
        if (btn_time_up.hold_count > 30) {
            interval = 50;  // 20 Hz after 3 seconds
        }
        if (btn_time_up.hold_count > 100) {
            interval = 25;  // 40 Hz after 10 seconds
        }
        
        if (now - btn_time_up.last_action_time >= interval) {
            int32_t adjustment = calculate_time_adjustment(btn_time_up.hold_count);
            time_offset_seconds += adjustment;
            btn_time_up.last_action_time = now;
            btn_time_up.hold_count++;
        }
    }
    
    // Handle time down
    if (btn_time_down.pressed) {
        uint32_t interval = 100;  // Base interval: 100ms
        
        if (btn_time_down.hold_count > 30) {
            interval = 50;
        }
        if (btn_time_down.hold_count > 100) {
            interval = 25;
        }
        
        if (now - btn_time_down.last_action_time >= interval) {
            int32_t adjustment = calculate_time_adjustment(btn_time_down.hold_count);
            time_offset_seconds -= adjustment;
            btn_time_down.last_action_time = now;
            btn_time_down.hold_count++;
        }
    }
}

/**
 * Handle brightness adjustment buttons
 */
void handle_brightness_buttons(void) {
    uint32_t now = to_ms_since_boot(get_absolute_time());
    
    // Process button states
    process_button(&btn_bright_up);
    process_button(&btn_bright_down);
    
    // Handle brightness up - faster repeat
    if (btn_bright_up.pressed) {
        uint32_t interval = 50;  // 50ms = 20 Hz (much faster!)
        
        // Even faster after holding for a bit
        if (btn_bright_up.hold_count > 10) {
            interval = 25;  // 40 Hz after 0.5 seconds
        }
        
        if (now - btn_bright_up.last_action_time >= interval) {
            if (brightness < 63) {
                brightness++;
            }
            btn_bright_up.last_action_time = now;
            btn_bright_up.hold_count++;
        }
    } else {
        btn_bright_up.hold_count = 0;
    }
    
    // Handle brightness down - faster repeat
    if (btn_bright_down.pressed) {
        uint32_t interval = 50;  // 50ms = 20 Hz
        
        if (btn_bright_down.hold_count > 10) {
            interval = 25;  // 40 Hz after 0.5 seconds
        }
        
        if (now - btn_bright_down.last_action_time >= interval) {
            if (brightness > 0) {
                brightness--;
            }
            btn_bright_down.last_action_time = now;
            btn_bright_down.hold_count++;
        }
    } else {
        btn_bright_down.hold_count = 0;
    }
}

/**
 * Initialize SPI and GPIO
 */
void init_hardware(void) {
    // Initialize stdio for printf (USB)
    stdio_init_all();
    
    // Initialize SPI
    spi_init(SPI_PORT, SPI_BAUDRATE);
    
    // Set SPI format: 8 bits, CPOL=0, CPHA=0, MSB first
    spi_set_format(SPI_PORT, 8, SPI_CPOL_0, SPI_CPHA_0, SPI_MSB_FIRST);
    
    // Initialize SPI pins
    gpio_set_function(PIN_SCK, GPIO_FUNC_SPI);
    gpio_set_function(PIN_MOSI, GPIO_FUNC_SPI);
    gpio_set_function(PIN_MISO, GPIO_FUNC_SPI);
    
    // Initialize CS/latch pin
    gpio_init(PIN_CS);
    gpio_set_dir(PIN_CS, GPIO_OUT);
    gpio_put(PIN_CS, 0);  // idle low
    
    // Initialize buttons
    init_buttons();
}

/**
 * Refresh the entire display (call this continuously)
 */
void refresh_display(void) {
    // Display all 13 digits
    for (uint8_t i = 0; i < NUM_DIGITS; i++) {
        send_display_digit(i);
    }
}

/**
 * Calculate and display clock time
 */
void clock_calculate_HMS(void) {
    // Get time in seconds
    uint64_t total_seconds = to_us_since_boot(get_absolute_time()) / 1000000ULL;
    
    // Add offset
    int64_t adjusted_seconds = (int64_t)total_seconds + time_offset_seconds;
    
    // Extract time components
    int hours = (adjusted_seconds / 3600) % 24;
    int minutes = (adjusted_seconds / 60) % 60;
    int seconds = adjusted_seconds % 60;
    
    // Handle negative offset
    if (hours < 0) hours += 24;
    if (minutes < 0) minutes += 60;
    if (seconds < 0) seconds += 60;

    //>> 16 shifts right by 16 bits = divides by 65536 seconds (~less than 18 hours)
    //& 0x7 masks to 3 bits = gives values 0-7
    //% 5 reduces to 0-4 range
    uint32_t pos_offset = ((adjusted_seconds >> 16) & 0x7) % 5;

    for(uint8_t i = 0; i < 4; i++) {
        if(pos_offset-i > 0) {
            set_digit_value(i, 10);
        }
        set_digit_value(i, 10);  // blank all digits initially
    }
    for(uint8_t i = 9; i < 13; i++) {
        if(pos_offset-i > 0) {
            set_digit_value(i, 10);
        }
        set_digit_value(i, 10);  // blank all digits initially
    }


    set_digit_value(4-pos_offset, 10);
    set_digit_value(5-pos_offset, hours / 10);
    set_digit_value(6-pos_offset, hours % 10);
    set_digit_value(7-pos_offset, 10);
    set_digit_value(8-pos_offset, minutes / 10);
    set_digit_value(9-pos_offset, minutes % 10);
    set_digit_value(10-pos_offset, 10);
    set_digit_value(11-pos_offset, seconds / 10);
    set_digit_value(12-pos_offset, seconds % 10);
}


int main(void) {
    init_hardware();

    special_m_enabled = false;
    special_dash_enabled = false;
    special_e_enabled = false;
    
    set_brightness(10);
    
    printf("Clock started\n");
    
    // Main loop
    while (true) {
        // Handle button inputs
        handle_time_buttons();
        handle_brightness_buttons();
        
        // Update and display clock
        clock_calculate_HMS();
        refresh_display();
    }
    
    return 0;
}

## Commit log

2025-11-04 silkscreen and production files
    [VFD display 1.kicad_pcb, bom.csv, designators.csv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]
2026-01-22 dir reupload
    [0C-138.SLDPRT, 1.15.SLDPRT, 2.SLDPRT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]
2026-01-22 Add README with VFD driver details
2026-01-22 Update README with dimming and heater adjustment details
    Added information about analog dimming and heater voltage adjustment.
